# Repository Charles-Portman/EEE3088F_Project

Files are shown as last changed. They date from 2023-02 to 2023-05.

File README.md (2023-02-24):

# EEE3088F_Project
 
The project will be a Self-Contained Light Sensing Module.
This will include an ambient light digital sensor and an analog voltage divider using photoresistors (Amount dependant on budget).
The module will include EEEPROM and battery power.
The prupose of the Git is for the programming of the microcontroller to FTDI-USB converter, EEPROM read and write, Reading from the sensors using I2C and the on-board ADC of the microcintroller.

NOTE - Additionally a low power standby mode may be added

Proposed branches 
- Sensors
 - ADC sensing
 - Digital Sensing
- Storage
- External Communication

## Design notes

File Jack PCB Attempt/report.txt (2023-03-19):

Info: Updated footprint R14 (OptoDevice:R_LDR_10x8.5mm_P7.6mm_Vertical): : (no changes)
Info: Updated footprint R16 (OptoDevice:R_LDR_10x8.5mm_P7.6mm_Vertical): : (no changes)
Info: Updated footprint R15 (OptoDevice:R_LDR_10x8.5mm_P7.6mm_Vertical): : (no changes)
Info: Updated footprint U2 (OptoDevice:Lite-On_LTR-303ALS-01): : (no changes)
Info: Updated footprint R17 (OptoDevice:R_LDR_10x8.5mm_P7.6mm_Vertical): : (no changes)
Info: Updated footprint U1 (OptoDevice:Lite-On_LTR-303ALS-01): : (no changes)

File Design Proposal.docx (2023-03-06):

# Light-Sensing HAT Design Proposal

Team Number:

Team Members:

- Jake Wesselink – WSSCAR008
- Jack Youens – YNSJAC001
- Charles Portman – PRTCHA018

# Submodule 1:

# Microcontroller Interfacing

# Specifications:

## Chip Connections:

### STM32F051C6T6

Pin Number | Connection
8 | GND
9 | +3.3V
23 | GND
24 | +3.3V
30 | RXD
31 | TXD
45 | SCL
46 | SDA
48 | +3.3V

### CH340G

Pin Number | Connection
1 | GND
2 | PA10
3 | PA9
5 | D+
6 | D-
16 | +3.3V

### AT24C256C-SSHL-T

Pin Number | Connection
4 | GND
5 | PB9
6 | PB8
8 | +3.3V

### MICROXNJ

Pin Number | Connection
1 | +3.3V
2 | UD-
3 | UD+
5 | GND

## Additional specifications:

The microcontroller must receive a varying voltage from 4 of its GPIO pins, as well as serial data from 1 of its GPIO pins. The microcontroller must convert these varying voltages into a digital value. The microcontroller must store these values in the EEPROM chip and must be able to retrieve this data. The microcontroller must send this data to the CH340G bridge interface when required. The subsystem must receive 5V DC from the MICROXNJ USB connector and must connect it to the power subsystem to be converted into 3.3V DC. The subsystem must run off 3.3V DC.

# Draft Bill Of Materials:

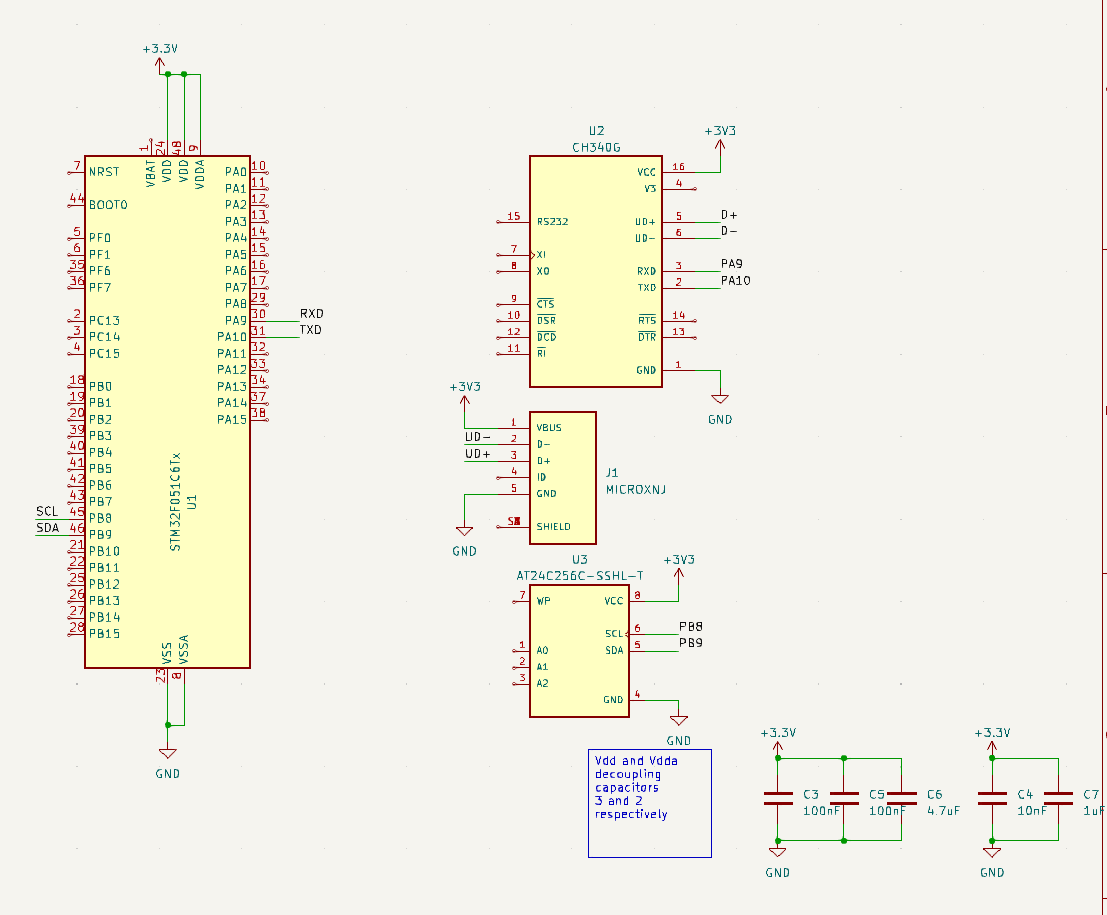
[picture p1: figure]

Component | Function | Price
MicroXNJ | USB 2.0 Female Connector | $0.03
AT24C256C-SSHL-T | EEPROM | $0.52
CH340G | UART to USB tranciever | $0.47

# Submodule Interfaces:

## MICROXNJ

This USB interface will receive 3.3V DC from the STM32F0C6T6 microcontroller, as well as data through two lines from the CH240G chip. The interface will send data through two lines.

## AT24C256C-SSHL-T

This EEPROM chip will receive 3.3V DC as well as a 12MHz clock signal and data from the STM32F051C6T6 microcontroller. The chip will send this data back to the microcontroller when requested.

## CH340G

This bridge interface chip will receive 3.3V DC, as well as data through two lines, from the STM32F0C6T6 microcontroller. The chip will send data to the MICROXNJ interface through two lines.

## STM32F051C6T6

This microcontroller chip will send to and receive data from the AT24C256C-SSHL-T EEPROM chip through two lines. The chip will receive 3.3V DC from the power subsystem. The chip will send data to the CH340G bridge interface chip through two lines.

Submodule 2:

# Power Subsystem

# Specifications:

- This submodule must be built around a single 5V 18650 Li-Ion battery.
- This battery must be held onto the board using a 18650 connector (Pt number – LCSC: C2988620).
- This battery must have a battery charger that takes 5V from the USB connection designed in the Microcontroller Interfacing and Coms submodule.
- This battery must have reverse polarity protection before powering the rest of the board.
- This battery must have under voltage protection, turning off the board if the battery voltage drops too low for the Voltage Regulator to handle.
- This battery must have a Voltage Regulator dropping the input voltage to 3.3V, which will be output to the rest of the board.

# Draft Bill Of Materials:

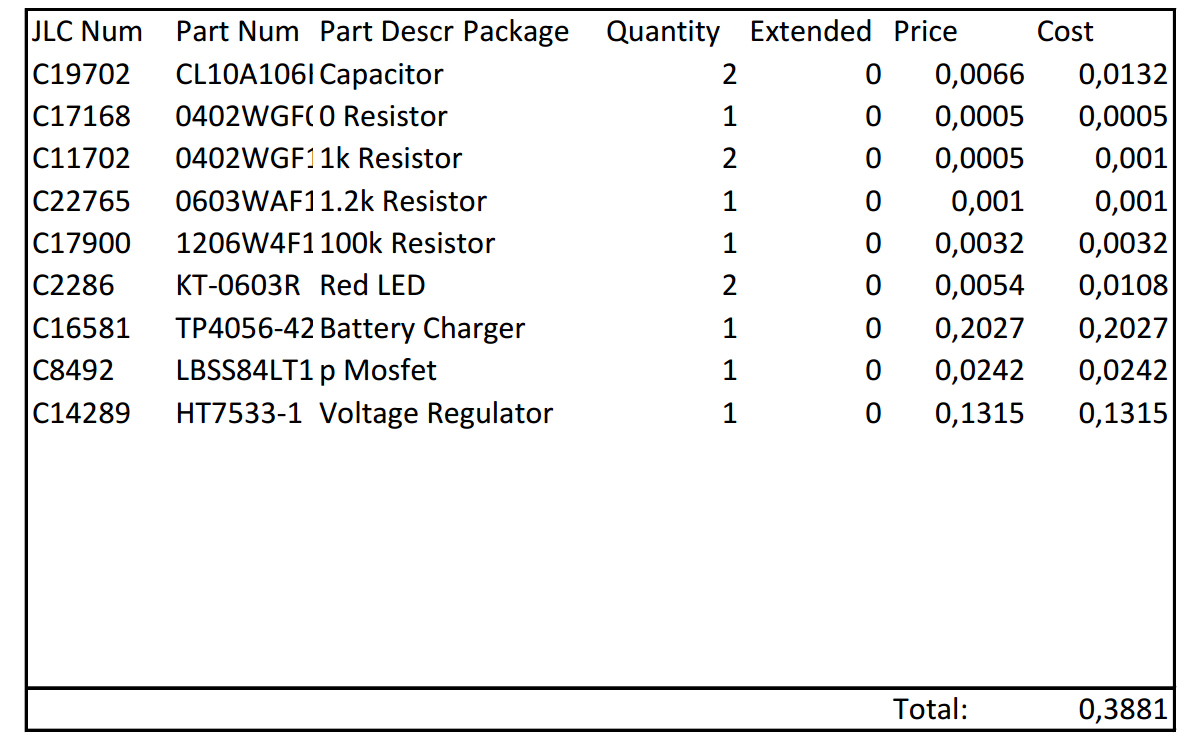
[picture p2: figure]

Link to GitHub spreadsheet: Link (https://github.com/Charles-Portman/EEE3088F_Project/tree/main/EEE3088) then select EEE3088_Power.csv

Schematic:

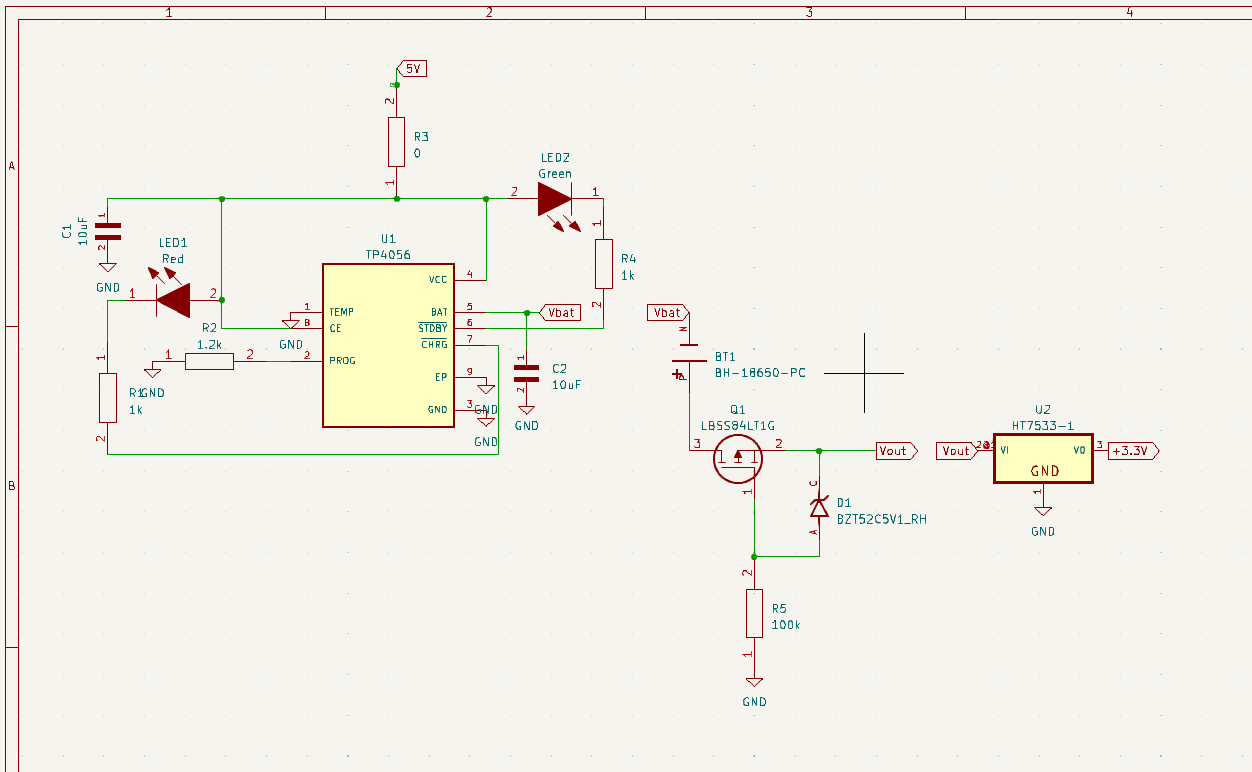
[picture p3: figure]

# Submodule Interfaces:

This Submodule must interface with the Microcontroller Submodule and draw 5V to the battery charger via the USB type A connection.

This Submodule must interface with both other Submodules by powering them with 3.3V through the voltage regulator.

This Submodule must interface with the outside world by having a pair of green and red LEDs, connected to the battery charger, to show when the battery is charging.

Submodule 3:

Sensing

Specifications:

Digital Sensor Specification:

The submodule contains an ambient light sensor measuring ambient light from 0.1 Lux to 64K Lux, it should receive +3.3V power and GND connections and will provide a I2C interface with an SCL input clock and SDA return both at 3.3V high.

Analogue Sensor Specification:

The submodule contains 2 light dependant resistors forming a voltage divider, it should receive +3.3V power and GND connections and will provide one analogue voltage return between 0 and +3.3V. The LDR voltage divider will provide directional information on the light.

Draft Bill of Materials:

Link to the Git Spreadsheet BOM: Link (https://github.com/Charles-Portman/EEE3088F_Project/blob/main/Sense_Costing.xlsx)

The total cost for this submodule as per the BOM comes to: $7.3208.

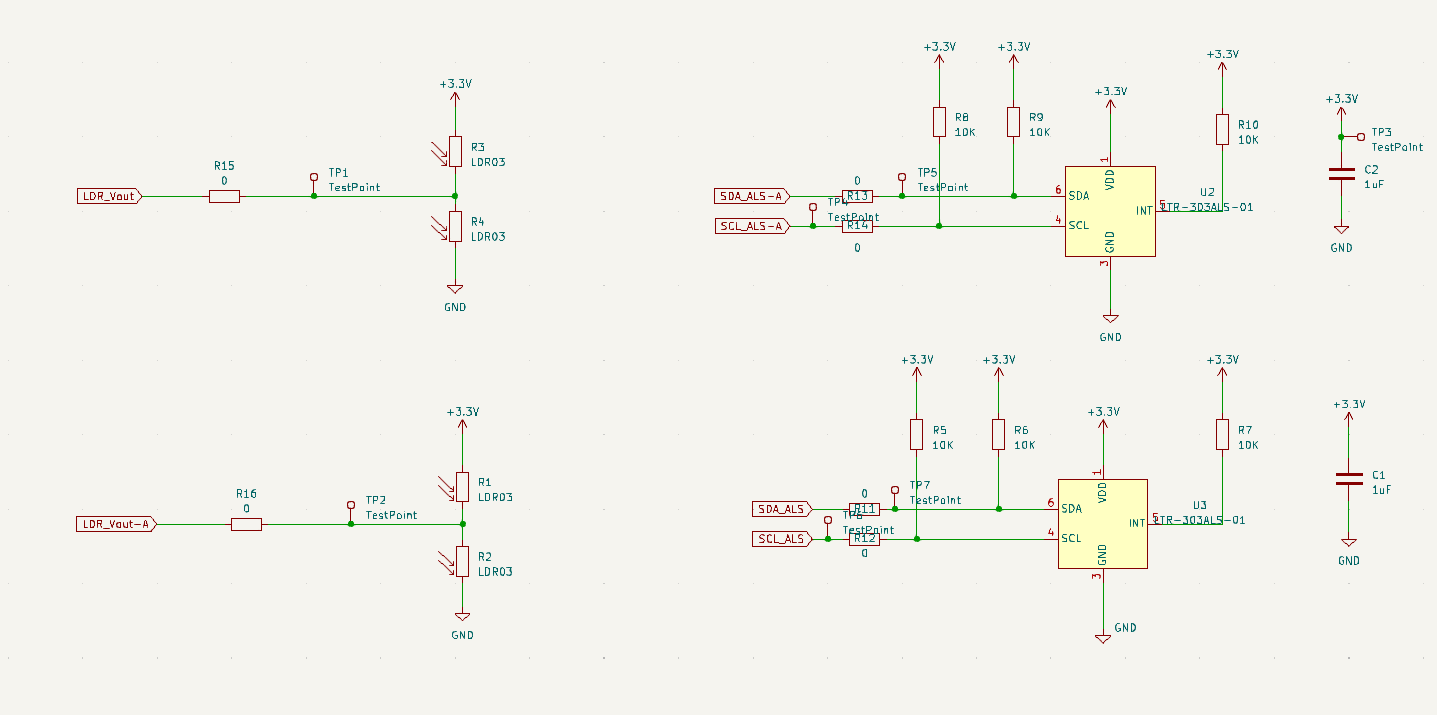
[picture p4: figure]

Schematic:

Submodule Interfacing:

Digital Sensor Interface:

The digital sensor will measure the ambient light levels of the surroundings from 0.1 Lux to 64K Lux and return the value as a 16 bit integer through the SDA_ALS line connected to pin 6 to the microcontroller unit (I2C Communication). The microcontroller will provide the SCL_ALS through pin 4 to the sensor.

Analogue Sensor Interface:s

The analogue sensor will interface with the microcontroller through the LDR_Vout line connected to the ADC of the microcontroller. The LDR voltage divider will provide directional information on the light.

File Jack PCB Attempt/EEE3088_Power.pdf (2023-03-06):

JLC Num Part Num Part Description Package Quantity Extended Price | Cost
C19702 | CL10A106KP8NNNC Capacitor | 2 | 0 | 0,0066 | 0,0132
C17168 | 0402WGF0000TCE 0 Resistor | 1 | 0 | 0,0005 | 0,0005
C11702 | 0402WGF1001TCE 1k Resistor | 2 | 0 | 0,0005 | 0,001
C22765 | 0603WAF1201T5E 1.2k Resistor | 1 | 0 | 0,001 | 0,001
C17900 | 1206W4F1003T5E 10k Resistor | 1 | 0 | 0,0032 | 0,0032
C2286 | KT-0603R Red LED | 2 | 0 | 0,0054 | 0,0108
C16581 | TP4056-42-ESOP8 Battery Charger | 1 | 0 | 0,2027 | 0,2027
C8492 | LBSS84LT1Gp Mosfet | 1 | 0 | 0,0242 | 0,0242
C14289 | HT7533-1 Voltage Regulator | 1 | 0 | 0,1315 | 0,1315
Total: | 0,3881

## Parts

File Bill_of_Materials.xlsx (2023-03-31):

Reference | Value | Footprint | Description | Extended | JLC Part Number | Manufacturer_Part_Number | Price | Qty | Price
C8 | 10nF | 10n Cap CL21B103KBANNNC:CAPC2012X140N | 10nF Cap 0805 | 0 | C1710 | CL21B103KBANNNC | 0.0085 | 1 | 0.0085
C7 | 4.7uF | 4.7n Cap LIB_0402B472K500NT:CAPC1005X55N | 4.7uF Cap 0805 | 0 | C1779 | CL21A475KAQNNNE | 0.0112 | 1 | 0.0112
LED1 | Red | MyRedLED:LEDC1608X70N | Red LED | 0 | C2286 | KT-0603R | 0.0054 | 1 | 0.0054
U3 | AT24C256C-SSHL-T | AT24C256C-SSHL-T EEPROM Chip:SOIC127P600X175-8N | EEPROM | 0 | C6482 | AT24C256C-SSHL-T | 0.4639 | 1 | 0.4639
Op-Amp1 | MCP6002T-I_SN | Myopamp:SOIC127P600X175-8N | Op-Amp | 0 | C7377 | MCP6002T-I/SN | 0.266 | 1 | 0.266
R14-R17 | LDR03 | OptoDevice:R_LDR_10x8.5mm_P7.6mm_Vertical | LDR | 1 | C11287 | GL3516 | 0.1298 | 4 | 3.5192
U4 | CH340G | CH340G Bridge:SOIC127P600X180-16N | USB Comms | 1 | C14267 | CH340G | 0.4733 | 1 | 3.4733
Voltage-Regulator-1, Voltage-Regulator-2 | HT7533-1 | HT7533-1:SOT89 | Voltage Regulator | 0 | C14289 | HT7533-1 | 0.1279 | 2 | 0.2558
P-Mos1 | AO3401A | MyPmos:SOT95P280X125-3N | 30V P-Channel MOSFET | 0 | C15127 | AO3401A | 0.0765 | 1 | 0.0765
C1, C2 | 10uF | CL10A106KP8NNNC:CAPC1608X90N | 10uF Cap 0805 | 0 | C15850 | CL21A106KAYNNNE | 0.0131 | 2 | 0.0262
Battery-Charger1 | TP4056 | TP4056:SOP127P600X175-9N | Battery Charger | 0 | C16581 | TP4056-42-ESOP8 | 0.2121 | 1 | 0.2121
R 2 | 1.2k | My1.2k:RESC1608X55N | 1.2k Resistor 0805 | 0 | C17379 | 0805W8F1201T5E | 0.0018 | 1 | 0.0018
R28, R29 | 1.8k | 1.8k Ohm Resistor:RESC2013X65N | 1.8k Res 0805 | 0 | C17398 | 0805W8F1801T5E | 0.0017 | 2 | 0.0034
R22-R27 | 10K | Resistor_SMD:R_0805_2012Metric | 10K Resistor 0805 | 0 | C17414 | 0805W8F1002T5E | 0.001 | 6 | 0.006
R4, R6, R8-R13, R18-R21, R30, R31 | 0 | Resistor_SMD:R_0402_1005Metric | 0 Res 0805 | 0 | C17477 | 0805W8F0000T5E | 0.0022 | 14 | 0.0308
R5, R32 | 1k | RESC1608X55N | 1k Res 0805 | 0 | C17513 | 0805W8F1001T5E | 0.0021 | 2 | 0.0042
R 7 | 1M | My1M:RESC2013X65N | 1M Resistor 0805 | 0 | C17514 | 0805W8F1004T5E | 0.0016 | 1 | 0.0016
N-Mos1 | AO3400A | MyNmos:SOT95P280X125-3N | 30V N-Channel MOSFET | 0 | C20917 | AO3400A | 0.0787 | 1 | 0.0787
Z1 | MM3Z5V6C | MyZener:SODFL2513X100N | Zener diode | 1 | C48886 | MM3Z5V6 | 0.0182 | 1 | 3.0182
C5, C6 | 100nF | 100n CC0603KRX7R9BB104:CAPC1608X90 | 100nF Cap 0805 | 0 | C49678 | CC0805KRX7R9BB104 | 0.0046 | 2 | 0.0092
LED2 | Green | MyGreenLED:LEDC1608X50N | Green LED | 0 | C72043 | 19-217/GHC-YR1S2/3T | 0.0264 | 1 | 0.0264
R 3 | 100k | My100k:RESC3116X65N | 100k Resistor 0805 | 0 | C149504 | 0805W8F1003T5E | 0.0017 | 1 | 0.0017
U1, U2 | LTR-303ALS-01 | OptoDevice:Lite-On_LTR-303ALS-01 | ALS | 1 | C364577 | LTR-303ALS-01 | 0.3762 | 2 | 3.7524
J1 | MICROXNJ | MICROXNJ:SHOUHAN_MICROXNJ | USB Connector | 1 | C404969 | MicroXNJ | 0.0333 | 1 | 3.0333
C3, C4, C9 | 1uF | Capacitor_SMD:C_0805_2012Metric | 1uF Cap 0805 | 1 | C2976902 | CA45B-A-16V-1UF-k | 0.0533 | 3 | 3.1599
Battery-Holder1 | BH-18650-PC | BH-18650-PC:BAT_BH-18650-PC | Battery Holder | 0 | DNP | DNP | 0 | 1 | 0
J2, J3 | Conn_01x24 | Connector_PinHeader_1.00mm:PinHeader_1x24_P1.00mm_Vertical | STM Connector | 0 | DNP | DNP | 0 | 2 | 0
TP1-TP14, TP19-TP22 | TestPoint | TestPoint:TestPoint_Pad_2.0x2.0mm | Test Point | 0 | DNP | DNP | 0 | 18 | 0
 |  |  |  |  |  |  |  |  | 21.4457 | 107.2285

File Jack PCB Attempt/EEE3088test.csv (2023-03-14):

Reference | Value | Datasheet | Description | Extended | Manufacturer_Part_Number | Price | Qty
Battery-Charger1 | TP4056 | https://datasheet.lcsc.com/lcsc/1809261820_TOPPOWER-Nanjing-Extension-Microelectronics-TP4056-42-ESOP8_C16581.pdf | Battery Charger | 0 | TP4056-42-ESOP8 | 0.2064 | 1
Battery-Holder1 | BH-18650-PC |  |  | 0 |  | 0.00 | 1
C1 | 10uF | https://datasheet.lcsc.com/lcsc/1810191219_Samsung-Electro-Mechanics-CL10A106KP8NNNC_C19702.pdf | 10uF Cap | 0 | CL10A106KP8NNNC | 0.0066 | 1
C2 | 10uF | https://datasheet.lcsc.com/lcsc/1810191219_Samsung-Electro-Mechanics-CL10A106KP8NNNC_C19702.pdf | 10uF Cap | 0 | CL10A106KP8NNNC | 0.0066 | 1
C3 | 1uF | https://datasheet.lcsc.com/lcsc/1810191216_Samsung-Electro-Mechanics-CL21B105KBFNNNE_C28323.pdf | 1uF Cap 0805 | 0 |  | 0.0087 | 1
C4 | 1uF | https://datasheet.lcsc.com/lcsc/1810191216_Samsung-Electro-Mechanics-CL21B105KBFNNNE_C28323.pdf | 1uF Cap 0805 | 0 |  | 0.0087 | 1
C5 | 100nF | https://datasheet.lcsc.com/lcsc/2211101700_YAGEO-CC0603KRX7R9BB104_C14663.pdf | 100nF Cap | 0 | CC0603KRX7R9BB104 | 0.01 | 1
C6 | 100nF | https://datasheet.lcsc.com/lcsc/2211101700_YAGEO-CC0603KRX7R9BB104_C14663.pdf | 100nF Cap | 0 | CC0603KRX7R9BB104 | 0.01 | 1
C7 | 4.7uF | https://datasheet.lcsc.com/lcsc/1810261822_Samsung-Electro-Mechanics-CL21A475KAQNNNE_C1779.pdf | 4.7uF | 0 | CL21A475KAQNNNE | 0.01 | 1
C8 | 10nF | https://datasheet.lcsc.com/lcsc/1811151136_Samsung-Electro-Mechanics-CL21B103KBANNNC_C1710.pdf | 10nF Cap | 0 | CL21B103KBANNNC | 0.01 | 1
C9 | 1uF | https://datasheet.lcsc.com/lcsc/1810191216_Samsung-Electro-Mechanics-CL21B105KBFNNNE_C28323.pdf | 1uF Cap 0805 | 0 |  | 0.0087 | 1
D1 | BZT52C5V1_RH |  |  |  |  |  | 1
J1 | MICROXNJ | https://datasheet.lcsc.com/lcsc/2204151400_SHOU-HAN-MicroXNJ_C404969.pdf | USB interface | 0 | MicroXNJ | 0.03 | 1
J2 | Conn_01x24 | ~ |  |  |  |  | 1
J3 | Conn_01x24 | ~ |  |  |  |  | 1
LED1 | Red | https://datasheet.lcsc.com/szlcsc/Hubei-KENTO-Elec-KT-0603R_C2286.pdf | Red LED for battery charging indication | 0 | KT-0603R | 0.0054 | 1
LED2 | Green | https://www.arrow.com/en/products/19-217ghc-yr1s23t/everlight-electronics | Green LED For battery charging indication | 0 | 19-217/GHC-YR1S2/3T | 0.0264 | 1
N-Mos1 | AO3400A | https://datasheet.lcsc.com/lcsc/1811081213_Alpha---Omega-Semicon-AO3400A_C20917.pdf | 30V N-Channel MOSFET | 0 | AO3400A | 0.0864 | 1
Op-Amp1 | MCP6002T-I_SN | https://datasheet.lcsc.com/lcsc/1811081213_Microchip-Tech-MCP6002T-I-SN--_C7377.pdf | Op-Amp | 0 | MCP6002T-I/SN | 0.282 | 1
P-Mos1 | AO3401A | https://datasheet.lcsc.com/lcsc/1810171817_Alpha---Omega-Semicon-AO3401A_C15127.pdf | 30V P-Channel MOSFET | 0 | AO3401A | 0.0797 | 1
R1 | 1k | https://datasheet.lcsc.com/szlcsc/Uniroyal-Elec-0402WGF1001TCE_C11702.pdf | 1k Resistor - 0402 | 0 | 0402WGF1001TCE | 0.0005 | 1
R2 | 1.2k | https://datasheet.lcsc.com/szlcsc/Uniroyal-Elec-0603WAF1201T5E_C22765.pdf | 1.2k Resistor - 0603 | 0 | 0603WAF1201T5E | 0.001 | 1
R3 | 100k | https://datasheet.lcsc.com/lcsc/2206010145_UNI-ROYAL-Uniroyal-Elec-1206W4F1003T5E_C17900.pdf | 100k Resistor - 1206 | 0 | 1206W4F1003T5E | 0.0032 | 1
R4 | 0 | https://www.mouser.in/datasheet/2/1365/1-3044649.pdf | Thick Film Resistors - SMD 0402 1/16W 1% 0R T/R-10000 |  | 0402WGF0000TCE |  | 1
R5 | 1k | https://datasheet.lcsc.com/szlcsc/Uniroyal-Elec-0402WGF1001TCE_C11702.pdf | 1K Resistor - 0402 | 0 | 0402WGF1001TCE | 0.0005 | 1
R6 | 0 | https://www.mouser.in/datasheet/2/1365/1-3044649.pdf | Thick Film Resistors - SMD 0402 1/16W 1% 0R T/R-10000 |  | 0402WGF0000TCE |  | 1
R7 | 1M | https://datasheet.lcsc.com/lcsc/2206010200_UNI-ROYAL-Uniroyal-Elec-0805W8F1004T5E_C17514.pdf | 1M Resistor - 0805 | 0 | 0805W8F1004T5E | 0.0016 | 1
R8 | 0 | https://www.mouser.in/datasheet/2/1365/1-3044649.pdf | Thick Film Resistors - SMD 0402 1/16W 1% 0R T/R-10000 |  | 0402WGF0000TCE |  | 1
R9 | 0 | https://www.mouser.in/datasheet/2/1365/1-3044649.pdf | Thick Film Resistors - SMD 0402 1/16W 1% 0R T/R-10000 |  | 0402WGF0000TCE |  | 1
R10 | 0 | https://www.mouser.in/datasheet/2/1365/1-3044649.pdf | Thick Film Resistors - SMD 0402 1/16W 1% 0R T/R-10000 |  | 0402WGF0000TCE |  | 1
R11 | 0 | https://datasheet.lcsc.com/lcsc/2206010216_UNI-ROYAL-Uniroyal-Elec-0402WGF0000TCE_C17168.pdf | 0 Resistor - 0402 | 0 | 0402WGF0000TCE | 0.0035 | 1
R12 | 0 | https://datasheet.lcsc.com/lcsc/2206010216_UNI-ROYAL-Uniroyal-Elec-0402WGF0000TCE_C17168.pdf | 0 Resistor - 0402 | 0 | 0402WGF0000TCE | 0.0035 | 1
R13 | 0 | https://datasheet.lcsc.com/lcsc/2206010216_UNI-ROYAL-Uniroyal-Elec-0402WGF0000TCE_C17168.pdf | 0 Resistor - 0402 | 0 | 0402WGF0000TCE | 0.0035 | 1
R14 | LDR03 | http://www.elektronica-https://datasheet.lcsc.com/lcsc/1810170710_JCHL-Shenzhen-Jing-Chuang-He-Li-Tech-GL3516-5-10K-_C11287.pdf | LDR | 1 | GL3516 | 0.13 | 1
R15 | LDR03 | http://www.elektronica-https://datasheet.lcsc.com/lcsc/1810170710_JCHL-Shenzhen-Jing-Chuang-He-Li-Tech-GL3516-5-10K-_C11287.pdf | LDR | 1 | GL3516 | 0.13 | 1
R16 | LDR03 | http://www.elektronica-https://datasheet.lcsc.com/lcsc/1810170710_JCHL-Shenzhen-Jing-Chuang-He-Li-Tech-GL3516-5-10K-_C11287.pdf | LDR | 1 | GL3516 | 0.13 | 1
R17 | LDR03 | http://www.elektronica-https://datasheet.lcsc.com/lcsc/1810170710_JCHL-Shenzhen-Jing-Chuang-He-Li-Tech-GL3516-5-10K-_C11287.pdf | LDR | 1 | GL3516 | 0.13 | 1
R18 | 0 | https://datasheet.lcsc.com/lcsc/2206010216_UNI-ROYAL-Uniroyal-Elec-0402WGF0000TCE_C17168.pdf | 0 Resistor - 0402 | 0 | 0402WGF0000TCE | 0.0035 | 1
R19 | 0 | https://datasheet.lcsc.com/lcsc/2206010216_UNI-ROYAL-Uniroyal-Elec-0402WGF0000TCE_C17168.pdf | 0 Resistor - 0402 | 0 | 0402WGF0000TCE | 0.0035 | 1
R20 | 0 | https://datasheet.lcsc.com/lcsc/2206010216_UNI-ROYAL-Uniroyal-Elec-0402WGF0000TCE_C17168.pdf | 0 Resistor - 0402 | 0 | 0402WGF0000TCE | 0.0035 | 1
R21 | 0 | https://datasheet.lcsc.com/lcsc/2206010216_UNI-ROYAL-Uniroyal-Elec-0402WGF0000TCE_C17168.pdf | 0 Resistor - 0402 | 0 | 0402WGF0000TCE | 0.0035 | 1
R22 | 10K | https://datasheet.lcsc.com/lcsc/2206010216_UNI-ROYAL-Uniroyal-Elec-0805W8F1002T5E_C17414.pdf | 10K Resistor 0805 | 0 | 0805W8F1002T5E | 0.001 | 1
R23 | 10K | https://datasheet.lcsc.com/lcsc/2206010216_UNI-ROYAL-Uniroyal-Elec-0805W8F1002T5E_C17414.pdf | 10K Resistor 0805 | 0 | 0805W8F1002T5E | 0.001 | 1
R24 | 10K | https://datasheet.lcsc.com/lcsc/2206010216_UNI-ROYAL-Uniroyal-Elec-0805W8F1002T5E_C17414.pdf | 10K Resistor 0805 | 0 | 0805W8F1002T5E | 0.001 | 1
R25 | 10K | https://datasheet.lcsc.com/lcsc/2206010216_UNI-ROYAL-Uniroyal-Elec-0805W8F1002T5E_C17414.pdf | 10K Resistor 0805 | 0 | 0805W8F1002T5E | 0.001 | 1
R26 | 10K | https://datasheet.lcsc.com/lcsc/2206010216_UNI-ROYAL-Uniroyal-Elec-0805W8F1002T5E_C17414.pdf | 10K Resistor 0805 | 0 | 0805W8F1002T5E | 0.001 | 1
R27 | 10K | https://datasheet.lcsc.com/lcsc/2206010216_UNI-ROYAL-Uniroyal-Elec-0805W8F1002T5E_C17414.pdf | 10K Resistor 0805 | 0 | 0805W8F1002T5E | 0.001 | 1
R28 | 1k | https://datasheet.lcsc.com/szlcsc/Uniroyal-Elec-0402WGF1001TCE_C11702.pdf | 1K Resistor - 0402 | 0 | 0402WGF1001TCE | 0.0005 | 1
R29 | 1k | https://datasheet.lcsc.com/szlcsc/Uniroyal-Elec-0402WGF1001TCE_C11702.pdf | 1K Resistor - 0402 | 0 | 0402WGF1001TCE | 0.0005 | 1
TP1 | TestPoint | ~ |  |  |  |  | 1
TP2 | TestPoint | ~ |  |  |  |  | 1
TP3 | TestPoint | ~ |  |  |  |  | 1
TP4 | TestPoint | ~ |  |  |  |  | 1
TP5 | TestPoint | ~ |  |  |  |  | 1
TP6 | TestPoint | ~ |  |  |  |  | 1
TP7 | TestPoint | ~ |  |  |  |  | 1
TP8 | TestPoint | ~ |  |  |  |  | 1
TP9 | TestPoint | ~ |  |  |  |  | 1
TP10 | TestPoint | ~ |  |  |  |  | 1
TP11 | TestPoint | ~ |  |  |  |  | 1
TP12 | TestPoint | ~ |  |  |  |  | 1
U1 | LTR-303ALS-01 | https://datasheet.lcsc.com/lcsc/1912111437_Lite-On-LTR-303ALS-01_C364577.pdf | ALS | 1 | LTR-303ALS-01 | 0.3887 | 1
U2 | LTR-303ALS-01 | https://datasheet.lcsc.com/lcsc/1912111437_Lite-On-LTR-303ALS-01_C364577.pdf | ALS | 1 | LTR-303ALS-01 | 0.3887 | 1
U3 | AT24C256C-SSHL-T | https://datasheet.lcsc.com/lcsc/1809151932_Microchip-Tech-AT24C256C-SSHL-T_C6482.pdf |  | 0 | AT24C256C-SSHL-T |  | 1
U4 | CH340G | https://datasheet.lcsc.com/lcsc/2008191806_WCH-Jiangsu-Qin-Heng-CH340G_C14267.pdf |  | 0 | CH340G | 0.47 | 1
Voltage-Regulator-1 | HT7533-1 | https://datasheet.lcsc.com/lcsc/1811062113_Holtek-Semicon-HT7533-1_C14289.pdf |  | 0 | HT7533-1 | 0.1315 | 1
Voltage-Regulator-2 | HT7533-1 | https://datasheet.lcsc.com/lcsc/1811062113_Holtek-Semicon-HT7533-1_C14289.pdf |  | 0 | HT7533-1 | 0.1315 | 1

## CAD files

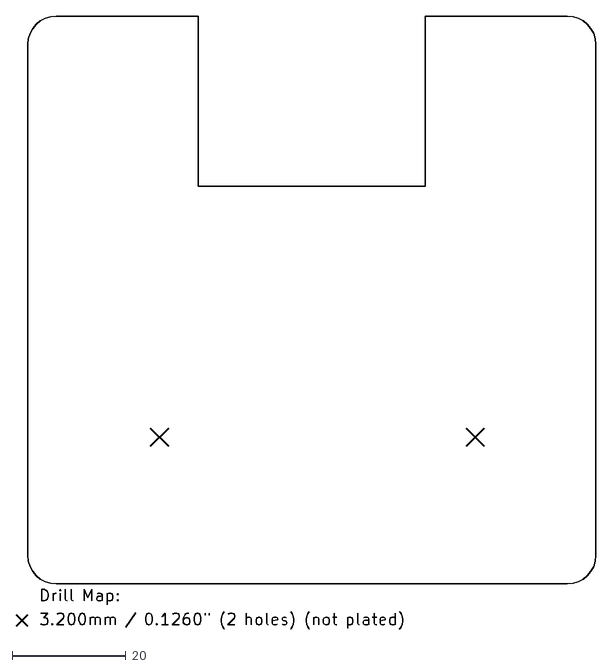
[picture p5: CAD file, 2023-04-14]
Final_Submission/Fianl_V1/EEE3088-NPTH-drl_map.dxf
102.0 x 107.9

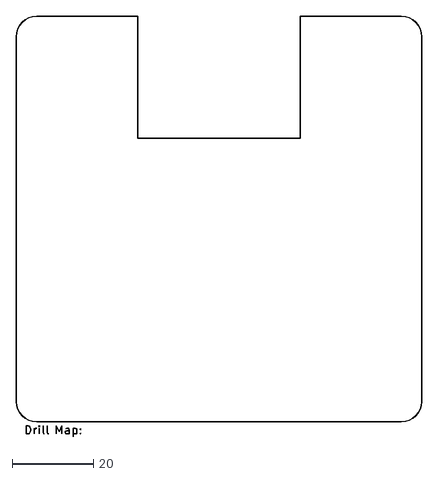
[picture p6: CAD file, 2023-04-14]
Final_Submission/Final_V2/EEE3088-NPTH-drl_map.dxf
100.0 x 103.7

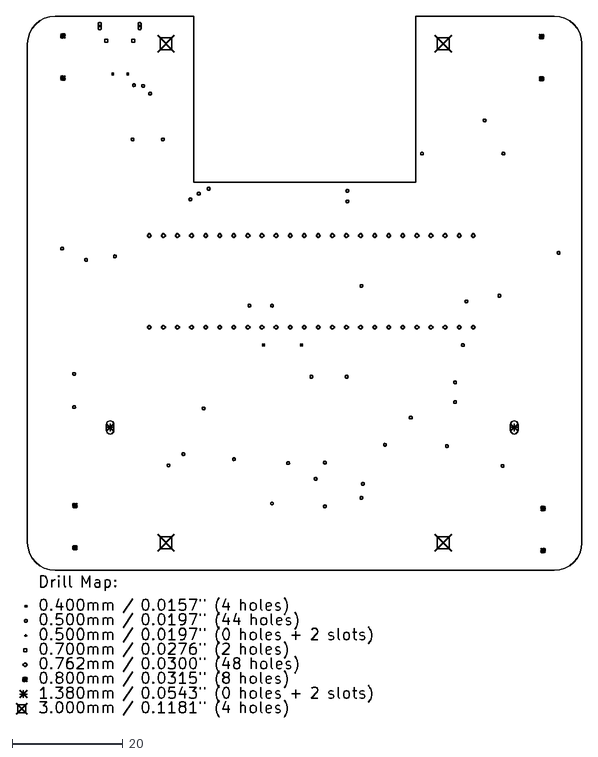
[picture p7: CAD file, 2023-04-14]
Final_Submission/Fianl_V1/EEE3088-PTH-drl_map.dxf
102.0 x 126.4

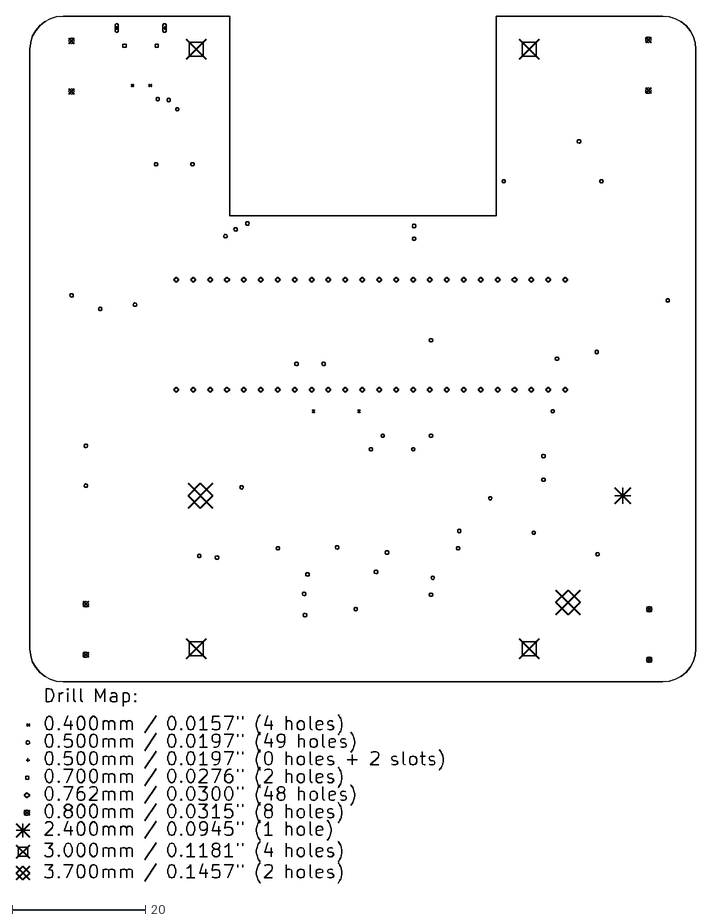
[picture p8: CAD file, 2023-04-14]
Final_Submission/Final_V2/EEE3088-PTH-drl_map.dxf
102.0 x 130.2

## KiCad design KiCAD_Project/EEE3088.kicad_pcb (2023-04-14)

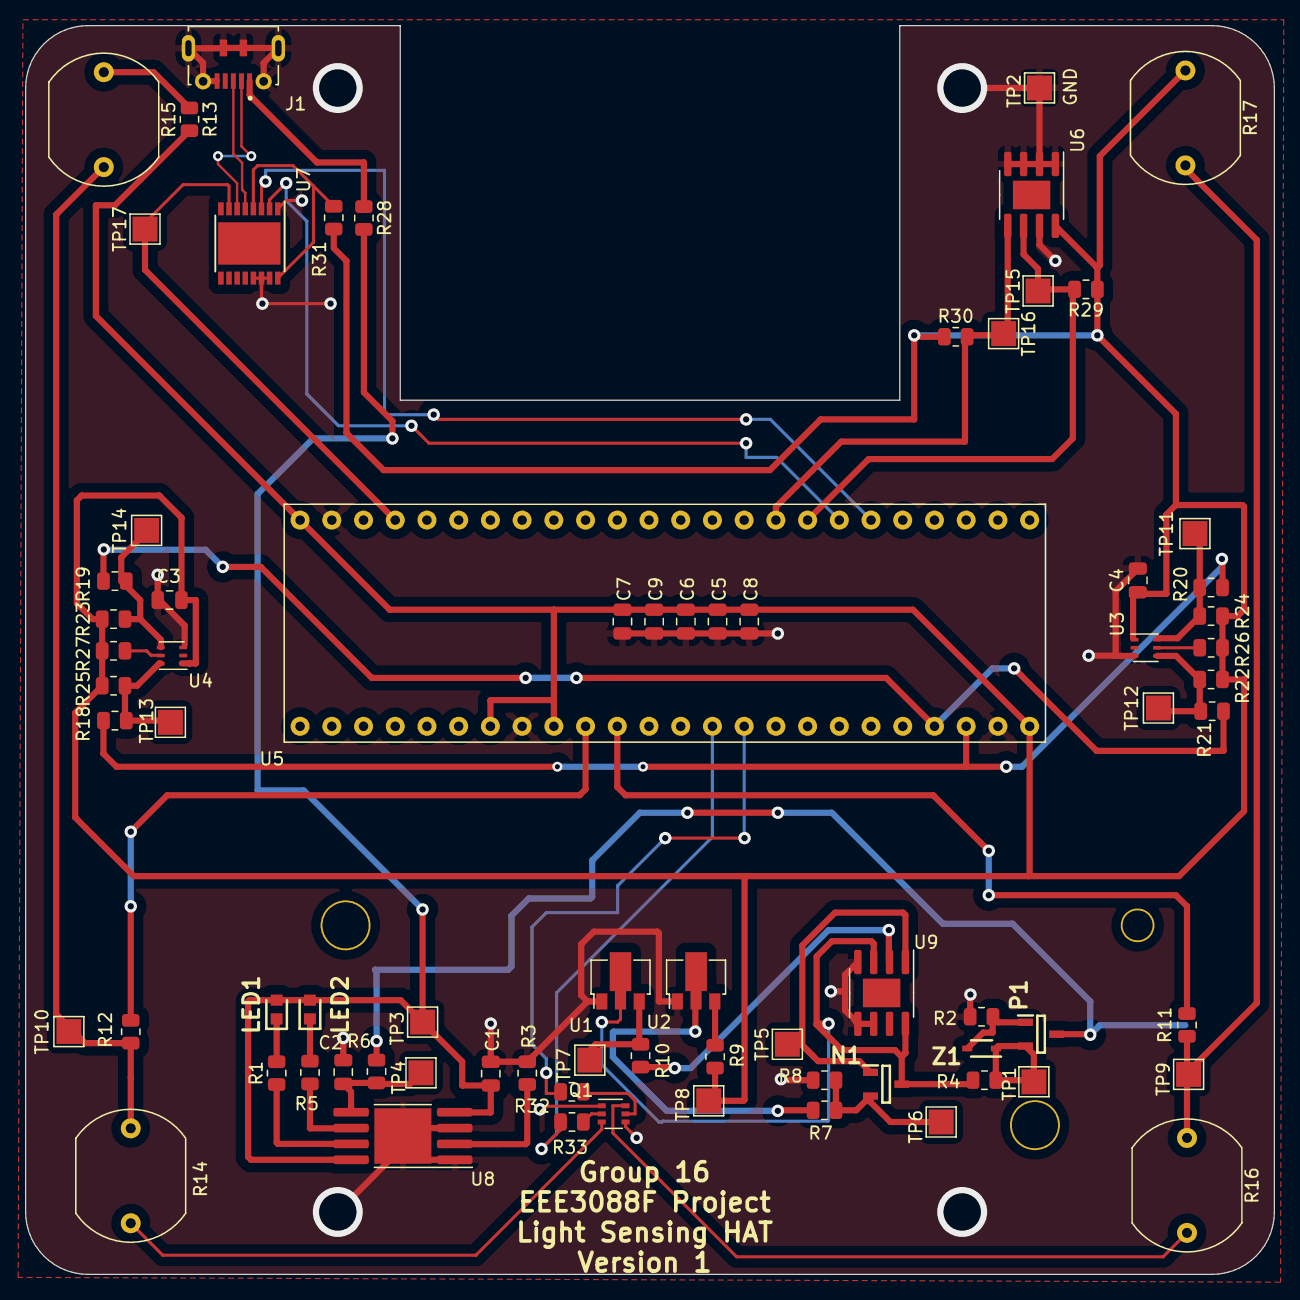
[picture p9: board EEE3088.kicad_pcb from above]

Board: 2 copper layers, 100.0 x 100.0 mm, 76 parts (1 on the bottom side), 47 nets.

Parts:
Battery-Holder1: BH-18650-PC; 18650_Holder_SMD
C1, C2: 10uF; C_0805_2012Metric
C3, C4, C9: 1uF; C_0805_2012Metric
C5, C6: 100nF; C_0805_2012Metric
C7: 4.7uF; C_0805_2012Metric
C8: 10nF; C_0805_2012Metric
J1: MICROXNJ; SHOUHAN_MICROXNJ
LED1: Red; LEDC1608X70N
LED2: Green; LEDC1608X50N
N1: AO3400A; SOT95P280X125-3N
P1: AO3401A; SOT95P280X125-3N
Q1: MMDT2222A; SOT-363_SC-70-6
R1, R5: 1k; R_0805_2012Metric
R2: 100k; R_0805_2012Metric
R3: 1.2k; R_0805_2012Metric
R4, R6, R7, R9, R10, R11, R12, R13, R18, R19, R20, R21, R28, R31: 0; R_0805_2012Metric
R8: 1M; R_0805_2012Metric
R14, R15, R16, R17: LDR03; R_LDR_10x8.5mm_P7.6mm_Vertical
R22, R23, R24, R25, R26, R27: 10K; R_0805_2012Metric
R29, R30: 1.8k; R_0805_2012Metric
R32, R33: 1K; R_0805_2012Metric
TP1, TP2, TP3, TP4, TP5, TP6, TP7, TP8, TP9, TP10, TP11, TP12, TP13, TP14, TP15, TP16, TP17: TestPoint; TestPoint_Pad_2.0x2.0mm
U1, U2: HT7533-1; SOT-89-3
U3, U4: LTR-303ALS-01; Lite-On_LTR-303ALS-01
U5: Header; STM32F051C6T6
U6: AT24C256C-SSHL-T; SOIC-8-1EP_3.9x4.9mm_P1.27mm_EP2.29x3mm
U7: CH340G; HTSSOP-16-1EP_4.4x5mm_P0.65mm_EP3.4x5mm
U8: TP4056; SOP-8-1EP_4.57x4.57mm_P1.27mm_EP4.57x4.45mm
U9: MCP6002T-I_SN; SOIC-8-1EP_3.9x4.9mm_P1.27mm_EP2.29x3mm
Z1: MM3Z5V6C; SODFL2513X100N

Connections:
+3.3V: C3.1, C4.1, C5.1, C6.1, C7.1, C8.1, C9.1, R9.2, R13.2, R17.1, R22.1, R23.1, R24.1, R25.1, R26.1, R27.1, R29.1, R30.1, R31.1, TP8.1, U3.1 (VDD), U4.1 (VDD), U5.7 (NRST), U5.9 (V+), U5.24 (V+), U5.48 (V+), U6.8 (VCC)
+5V: C1.1, LED1.2, LED2.2, R28.2, TP3.1, U8.4 (VCC), U8.8 (CE)
/Microcontroller/Analogue_Enable1: R33.1, U5.14 (PA4)
/Microcontroller/Analogue_Enable2: R32.1, U5.15 (PA5)
/Microcontroller/EEPROM_SCL: R29.2, TP15.1, U5.32 (PA11), U6.6 (SCL)
/Microcontroller/EEPROM_SDA: R30.2, TP16.1, U5.33 (PA12), U6.5 (SDA)
/Microcontroller/LDR_Vout1: R11.2, U5.11 (PA1)
/Microcontroller/LDR_Vout2: R12.1, U5.10 (PA0)
/Microcontroller/SCLSense: R19.1, R21.1, U5.21 (PB10)
/Microcontroller/SDASense_1: R18.1, R20.2, U5.22 (PB11)
/Microcontroller/USB_D+: J1.3 (D+), U7.5 (UD+)
/Microcontroller/USB_D-: J1.2 (D-), U7.6 (UD-)
/Microcontroller/USB_RXD: U5.30 (PA9), U7.3 (RXD)
/Microcontroller/USB_TIMIN: TP17.1, U5.45 (PB8), U7.7 (XI)
/Microcontroller/USB_TXD: U5.31 (PA10), U7.2 (TXD)
/Power_Subsystem/3.3-back: R10.2, U9.2 (VINA-)
/Power_Subsystem/V-Reg: R7.2, U2.2 (VI)
/Power_Subsystem/V-pos: N1.3, R4.2, U1.2 (VI), U9.3 (VINA+), U9.8 (VDD)
/Power_Subsystem/Vbat: Battery-Holder1.1, P1.3, R6.2
GND: Battery-Holder1.2, C1.2, C2.2, C3.2, C4.2, C5.2, C6.2, C7.2, C8.2, C9.2, J1.5 (GND), J1.S1 (SHIELD), J1.S2 (SHIELD), J1.S3 (SHIELD), J1.S4 (SHIELD), J1.S5 (SHIELD), J1.S6 (SHIELD), Q1.1 (E1), Q1.4 (E2), R2.1, R3.1, R8.2, TP2.1, U1.1, U2.1, U3.3 (GND), U4.3 (GND), U5.8 (GND), U5.23 (GND), U5.47 (GND), U6.1 (A0), U6.2 (A1), U6.3 (A2), U6.4 (GND), U6.7 (WP), U7.1 (GND), U7.13 (~DTR), U7.14 (~RTS), U7.15 (RS232), U8.1 (TEMP), U8.3 (GND), U8.9 (EP), U9.4 (VSS), U9.5 (VINB+), U9.6 (VINB-)
unnamed: J1.1 (VBUS), R28.1
unnamed: LED1.1, R1.2
unnamed: LED2.1, R5.1
unnamed: N1.2, R7.1, R8.1, TP6.1
unnamed: Q1.2 (B1), R33.2
unnamed: Q1.6 (C1), R16.2
unnamed: Q1.5 (B2), R32.2
unnamed: Q1.3 (C2), R14.2
unnamed: R11.1, R16.1, R17.2, TP9.1
unnamed: R12.2, R14.1, R15.2, TP10.1
unnamed: R13.1, R15.1
unnamed: R10.1, TP7.1, U1.3 (VO)
unnamed: R9.1, U2.3 (VO)
unnamed: R26.2, U3.5 (INT)
unnamed: R21.2, R22.2, TP12.1, U3.4 (SCL)
unnamed: R20.1, R24.2, TP11.1, U3.6 (SDA)
unnamed: R27.2, U4.5 (INT)
unnamed: R19.2, R23.2, TP14.1, U4.4 (SCL)
unnamed: R18.2, R25.2, TP13.1, U4.6 (SDA)
unnamed: R31.2, U7.4 (V3), U7.16 (VCC)
unnamed: C2.1, R6.1, TP4.1, U8.5 (BAT)
unnamed: R3.2, U8.2 (PROG)
unnamed: R1.1, U8.7 (~CHRG)
unnamed: R5.2, U8.6 (~STDBY)
unnamed: N1.1, TP5.1, U9.1 (VOUTA)
unnamed: P1.1, R2.2, Z1.2 (A)
unnamed: P1.2, R4.1, TP1.1, Z1.1 (K)

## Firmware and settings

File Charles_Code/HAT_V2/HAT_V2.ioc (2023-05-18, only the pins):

Mcu.UserName=STM32F051C6Tx
PA0.Signal=ADC_IN0
PA1.Signal=ADC_IN1
PA10.Signal=USART1_RX
PA4.Signal=GPIO_Output
PA5.Signal=GPIO_Output
PA9.Signal=USART1_TX

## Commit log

2023-03-03 KiCAD FIles
    [EEE3088.kicad_pcb, EEE3088.kicad_sch, Microcontroller_kicad_sch.kicad_sch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]
2023-03-03 First night - c
    [Microcontroller_kicad_sch.kicad_sch, Sensing_kicad_sch.kicad_sch]
2023-03-05 Microcontroller Comms
    Finished my subsection
    [Microcontroller_kicad_sch.kicad_sch]
2023-03-05 added BOM sensing
    [Sense_Costing.xlsx]
2023-03-06 Updated design proposal Q3
    [Sense_Costing.xlsx]
2023-03-06 Updated Sense_cost
    [Sense_Costing.xlsx]
2023-03-06 Power Updates
    Updated part values
    Made a Excel sheet for BOM
    [EEE3088.csv, EEE3088_Power.csv]
2023-03-06 Proposal update
    Power update
    [Microcontroller_kicad_sch.kicad_sch, Power_kicad_sch.kicad_sch, Sensing_kicad_sch.kicad_sch]
2023-03-11 Power update
    included Low voltage reg
    [EEE3088.csv, EEE3088.kicad_sch, Microcontroller_kicad_sch.kicad_sch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]
2023-03-12 power updates
    [Power_kicad_sch.kicad_sch]
2023-03-12 New microcontroller section
    Finished and neatened up
    [Microcontroller_kicad_sch.kicad_sch]
2023-03-12 better microcontroller sheet
    [EEE3088.kicad_sch, Microcontroller_kicad_sch.kicad_sch]
2023-03-12 power edit
    [EEE3088.csv, EEE3088.kicad_sch, Microcontroller_kicad_sch.kicad_sch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]
2023-03-12 updated BOM
    [Microcontroller_kicad_sch.kicad_sch, Sensing_kicad_sch.kicad_sch]
2023-03-14 BOM attempt
    [EEE3088.csv, EEE3088_EXPORT.csv, EEE3088_Final.csv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]
2023-03-14 BOM Update
    [Microcontroller_kicad_sch.kicad_sch, Power_kicad_sch.kicad_sch, Sensing_kicad_sch.kicad_sch]
2023-03-16 Added test points & 0 Ohm
    [Microcontroller_kicad_sch.kicad_sch, Sensing_kicad_sch.kicad_sch]
2023-03-16 Power - zener
    [Power_kicad_sch.kicad_sch]
2023-03-17 Start of PCB
    [EEE3088.kicad_pcb]
2023-03-17 Light update to power
    [Power_kicad_sch.kicad_sch]
2023-03-19 attempt to assign footprints
    [Microcontroller_kicad_sch.kicad_sch, Power_kicad_sch.kicad_sch, Sensing_kicad_sch.kicad_sch]
2023-03-19 adding footprints power
    [Power_kicad_sch.kicad_sch]
2023-03-19 Started Microcontroller PCB
    [EEE3088.kicad_pcb, Microcontroller_kicad_sch.kicad_sch]
2023-03-20 Finished uC PCB connections
    Your mom helped
    [EEE3088.kicad_pcb]
2023-03-20 uC parts added onto PCB properly
    [EEE3088.kicad_pcb, Microcontroller_kicad_sch.kicad_sch]
2023-03-20 Power PCB edit
    [EEE3088.kicad_pcb]
2023-03-20 Power wires
    [EEE3088.kicad_pcb]
2023-03-20 PCB_Update- DO NOT MOVE THE FREAKIN SENSORS
    [EEE3088.kicad_pcb, EEE3088.kicad_sch, Microcontroller_kicad_sch.kicad_sch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]
2023-03-20 power wiring
2023-03-20 power wriring
    [EEE3088.kicad_pcb]
2023-03-21 uC PCB routing except power
    [EEE3088.kicad_pcb]
2023-03-21 Power lines
    [EEE3088.kicad_pcb]
2023-03-21 Gerbers added
    [EEE3088-B_Cu.gbr, EEE3088-B_Mask.gbr, EEE3088-B_Paste.gbr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]
2023-03-27 Made a copy of the PCB
    [Copy of EEE3088-B_Cu.gbr, Copy of EEE3088-B_Mask.gbr, Copy of EEE3088-B_Paste.gbr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]
2023-03-27 Finished adding test copy for myself
    [Copy of EEE3088-B_Cu.gbr, Copy of EEE3088-B_Mask.gbr, Copy of EEE3088-B_Paste.gbr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]
2023-03-27 Revert "Finished adding test copy for myself"
    This reverts commit 9deb3b97d8caa0a97fc282a8a19962864a0c81f9.
    [Copy of EEE3088-B_Cu.gbr, Copy of EEE3088-B_Mask.gbr, Copy of EEE3088-B_Paste.gbr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]
2023-03-27 PCB H design attempt
    [Copy of EEE3088.kicad_pcb]
2023-03-31 Schematic updates
    [EEE3088.kicad_sch, EEE3088_Final.csv, EEE3088_Final.xlsx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]
2023-04-01 Schematic + PCB Update
    [EEE3088.kicad_pcb, EEE3088.kicad_sch, Microcontroller_kicad_sch.kicad_sch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]
2023-04-02 PCB continued again
    [EEE3088.kicad_pcb, Microcontroller_kicad_sch.kicad_sch, Power_kicad_sch.kicad_sch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]
2023-04-02 PCD- stm header added
    [EEE3088.kicad_pcb, Microcontroller_kicad_sch.kicad_sch, Power_kicad_sch.kicad_sch]
2023-04-02 Silkscreen changes
    [EEE3088.kicad_pcb]
2023-04-03 PCB - POwer and MCU added
    [EEE3088.kicad_pcb]
2023-04-03 GND connections updated
    [EEE3088.kicad_pcb]
2023-04-03 Added group number and names
    [EEE3088.kicad_pcb]
2023-04-03 Fixed Text
    [EEE3088.kicad_pcb]
2023-04-14 Battery footprint changed
    [EEE3088.kicad_pcb, Microcontroller_kicad_sch.kicad_sch, Power_kicad_sch.kicad_sch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]
2023-04-14 Gebs V2 + Github cleanup
    [BOM_V1_Schematic.xlsx, Bill of Materials.csv, Bill_of_Materials.xlsx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]
